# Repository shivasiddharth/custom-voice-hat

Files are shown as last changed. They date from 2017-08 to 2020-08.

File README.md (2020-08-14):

# custom-voice-hat
Create a custom Voice HAT, much like Google's VOICE HAT  

Use the below video for reference.     

<a href="http://www.youtube.com/watch?feature=player_embedded&v=GM1YbNMauck
" target="_blank">Detailed Youtube Video</a>

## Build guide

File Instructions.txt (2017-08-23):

# Parts List
1. Adafruit I2S MEMS Microphone Breakout - SPH0645LM4H - 2Nos - https://www.adafruit.com/product/3421
2. Adafruit I2S 3W Class D Amplifier Breakout - MAX98357A - 1No - https://www.adafruit.com/product/3006
3. Adafruit Perma-Proto HAT for Pi Mini Kit - With EEPROM - 1No - https://www.adafruit.com/product/2314

# Following steps to be completed on the Pi.

#Clone the project onto the pi
git clone https://github.com/shivasiddharth/custom-voice-hat

1. Turn on i2s support in /boot/config.txt with:
sudo nano /boot/config.txt

****Uncomment the following****
#dtparam=i2s=on
#dtparam=i2c_arm=on
#dtparam=spi=on
#dtparam=audio=on

****Add the following new entry****
dtparam=i2c_vc=on

Save Exit and Reboot.

2. Check for the Hats folder:
cd /proc/device-tree/

3. Open a new terminal and change directory to eepromutils:
cd /home/pi/custom-voice-hat/eepromutils

4. Make the EEPROM flasher executable and Flash the EEPROM with the eeprom file:
sudo chmod +x ./eepflash.sh
sudo ./eepflash.sh -w -f=voicehat.eep -t=24c32

5. Update raspberry pi kernels:
sudo apt-get update
sudo apt-get install raspberrypi-kernel

6. Reboot
sudo reboot

7. Check if your HAT is recognized,:
cd /proc/device-tree/

***YOU WILL HAVE A HAT FOLDER NOW WITH VOICE HAT DETAILS***

# Shutdown and Wire the Parts as indicated in the attached wiring diagram
***CAUTION- Amplifier board should be powered using 5V and the Mics using 3.3v***

# Start your Pi and move into the audio configuration scripts:
cd /home/pi/custom-voice-hat/audio-config/scripts/

#Make the scripts executable:
sudo chmod +x ./custom-voice-hat.sh
sudo chmod +x ./install-i2s.sh

#Run the Executable scripts
sudo ./custom-voice-hat.sh
sudo ./install-i2s.sh

****RUN THE custom-voice-hat.sh script untill you get .bak notification****
****REBOOT and Enjoy your HAT****

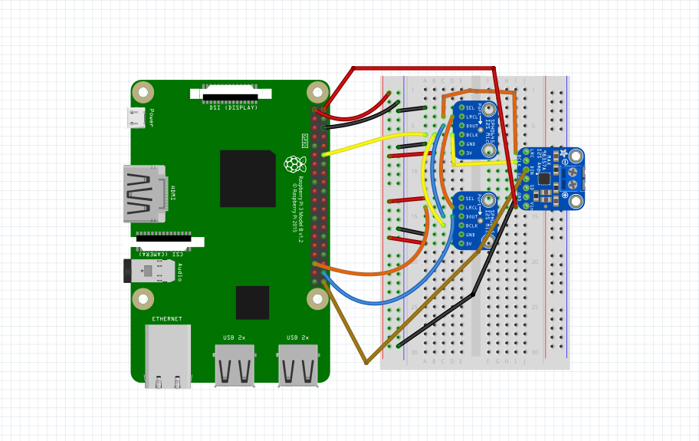
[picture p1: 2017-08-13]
Rpi-custom-voice-hat-wiring.png

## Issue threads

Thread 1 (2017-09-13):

Card 0 not found

kunallanjewar, 2017-09-13:
I followed the given instructions but getting following errors when I ran _./main.py -T ok-google_

Do I need to follow these instructions to install I2C microphone drivers?
https://learn.adafruit.com/adafruit-i2s-mems-microphone-breakout/raspberry-pi-wiring-and-test

**Error Log:**
[2017-09-12 22:22:27,683] INFO:recorder:started recording
[2017-09-12 22:22:27,714] INFO:main:ready...
Press the button on GPIO 23 then speak, or press Ctrl+C to quit...
ALSA lib confmisc.c:768:(parse_card) cannot find card '0'
ALSA lib conf.c:4259:(_snd_config_evaluate) function snd_func_card_driver returned error: No such file or directory
ALSA lib confmisc.c:392:(snd_func_concat) error evaluating strings
ALSA lib conf.c:4259:(_snd_config_evaluate) function snd_func_concat returned error: No such file or directory
ALSA lib confmisc.c:1251:(snd_func_refer) error evaluating name
ALSA lib conf.c:4259:(_snd_config_evaluate) function snd_func_refer returned error: No such file or directory
ALSA lib conf.c:4738:(snd_config_expand) Evaluate error: No such file or directory
ALSA lib pcm.c:2239:(snd_pcm_open_noupdate) Unknown PCM dsnoop
arecord: main:722: audio open error: No such file or directory
[2017-09-12 22:22:27,848] ERROR:recorder:Microphone recorder died unexpectedly, aborting...

kunallanjewar, 2017-09-13:
Figured it out. I had google-voice-hat commented in config.txt

Closed 2017-09-13.

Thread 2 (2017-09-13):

Only one mic is working?

kunallanjewar, 2017-09-13:
I followed all instruction and made sure i followed them currently, including the wiring of both microphones and the amp.

However, when I run following command, I can only see one mic working. I was wondering if both mics work for you?

`arecord -D plughw:0 -c2 -r 48000 -f S32_LE -t wav -V stereo -v file_stereo.wav`

shivasiddharth, 2017-09-27:
Sorry for getting back late. Missed this somehow.
I had the same suspicion , so i checked out the original AIY HAT that i have me just after i got his custom HAT done. Even in that, two channels are multiplexed into one. The google assistant does not recognize stereo microphone audio. May be thats the reason they have done this intentionally. Or the speaker amp sharing the clock pulse also could be the reason.

Closed 2018-02-20.

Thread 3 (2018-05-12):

which info is stored in the voicehat.eep file?

nivw, 2018-05-12:
Hi Sid,
I am looking to use a microphone and a speaker with I2S, as you did here.
I found little info on the web, on how to achieve this, and many folks asked about it.
So I looked to see what you used in your voicehat.eep.
I read [This](https://github.com/raspberrypi/hats/blob/master/eeprom-format.md) and can understand the first part of the eeprom:
` hexdump -C voicehat.eep
00000000  52 2d 50 69 01 00 02 00  7c 00 00 00 01 00 00 00  |R-Pi....|.......|
00000010  40 00 00 00 5e 69 95 06  36 73 da 92 91 42 be 31  |@...^i..6s...B.1|
00000020  52 b7 df 0d 01 00 01 00  0c 1c 47 6f 6f 67 6c 65  |R.........Google|
00000030  2c 20 49 6e 63 2e 47 6f  6f 67 6c 65 20 41 49 59  |, Inc.Google AIY|
00000040  20 61 75 64 69 6f 48 41  54 20 42 6f 61 72 64 20  | audioHAT Board |
00000050  76 31 92 90 02 00 01 00  20 00 00 00 00 00 00 00  |v1...... .......|
00000060  00 00 00 00 00 00 00 00  00 00 00 00 00 00 00 00  |................|
00000070  00 00 00 00 00 00 00 00  00 00 ed 6e ff ff ff ff  |...........n....|
00000080  ff ff ff ff ff ff ff ff  ff ff ff ff ff ff ff ff  |................|
*
00001000
`

Your vendor info atom data is clear, but I don't understand the GPIO and the device tree. in facat I see no device tree 0x0003 type at all.
So what is the GPIO setup and what device tree do you use?
Thank you very much for sharing this great project.
Niv

diabl0w, 2020-08-14:
hi, did you ever get this to work? I am trying to get the microphones and speaker output over i2s at the same time, but my speakers arent working. I can't tell if its a wiring issue or an eeprom issue or a kernel limitation issue

shivasiddharth, 2020-08-14:
@diabl0w I am still using the same custom hat even after so many updates and upgrades to the OS. I first flashed the EEPROM before wiring anything. And then went through the audio setup process. At this point if the flashing was done properly, you should see the DAC listed when you use the `asound -l` and `arecord -l` commands. Also, you should see the device tree. Only after verifying this you should wire the parts. I have shown this all in the video attached in the README.

shivasiddharth, 2020-08-14:
Try the method here if you are not using the EEPROM https://www.hackster.io/maremoto/snips-assistant-for-emergencies-safe-c3c178#toc-satellite-preparation-3

diabl0w, 2020-08-14:
> @diabl0w I am still using the same custom hat even after so many updates and upgrades to the OS. I first flashed the EEPROM before wiring anything. And then went through the audio setup process. At this point if the flashing was done properly, you should see the DAC listed when you use the `asound -l` and `arecord -l` commands. Also, you should see the device tree. Only after verifying this you should wire the parts. I have shown this all in the video attached in the README.

Thank you so much! I got it working and I am loving it! One problem I am having:

If I use a pcm5102a DAC both microphone and speaker work great! However, I wanted to use a better DAC, so I tried using an "Allo Boss" clone. If I use that, i only either get microphone or speaker, never both. Because the Allo Boss requires its own "dtoverlay", so whatever one i put second in "/boot/config.txt" works. The AlloBoss does not have its own eeprom, but it does use SDA/SCL, but at a different address (0x4d) and not our address of 0x50

diabl0w, 2020-08-14:
Okay, I think I know the issue. The issue is that the Allo Boss uses PCM5122. The PCM5122 can use i2s either over the actual i2s interface or i2s via spi. The allo boss has it configured to use the native i2s-1 pins (pins 3 and 5 on pi). The PCM5102 on the other hand uses i2s over spi.

So, that is the problem, but I do not know the solution. Can our hat coexist with the allo boss both using actual i2s? Or I can pull one of the headers on the Allo Boss to high which will make it work in spi mode like the pcm5102.

Id rather not have to modify the Allo Boss board

shivasiddharth, 2020-08-14:
Do check the pinout for that Allo DAC to see if there is any overlap with the Mics. You cna use other DACs like pHAT DAC, etc. I have tested it and it works. https://www.youtube.com/watch?v=m2aSVqBKY4Y

diabl0w, 2020-08-14:
The issue has something to do with

> pHAT DAC

yes, that is because that dac also uses the "PCM5102". The issue I am running into is that the Allo Boss uses a PCM5122, and it also has its own clock. I think the solution would be creating a custom dtoverlay/dts. Unfortunately, that is over my head of knowledge. But thank you for your help, I am still quite satisfied with the setup you provided :)

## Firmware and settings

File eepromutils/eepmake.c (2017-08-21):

/*
 *	Parses EEPROM text file and createds binary .eep file
 *	Usage: eepmake input_file output_file
*/

#include <stdio.h>
#include <stdlib.h>
#include <ctype.h>
#include <string.h>
#include <stdbool.h>
#include <fcntl.h>

#include "eeptypes.h"

#define HEADER_SIGN 0x69502d52 //"R-Pi" in ASCII reversed for endianness

//todo: larger initial mallocs

struct header_t header;
struct atom_t *custom_atom, vinf_atom, gpio_atom, dt_atom;
struct vendor_info_d* vinf;
struct gpio_map_d* gpiomap;

bool product_serial_set, product_id_set, product_ver_set, vendor_set, product_set, 
			gpio_drive_set, gpio_slew_set, gpio_hysteresis_set, gpio_power_set;
			
bool data_receive, has_dt, receive_dt;
			
char **data;
char *current_atom; //rearranged to write out
unsigned int data_len, custom_ct, total_size, data_cap, custom_cap;


int write_binary(char* out) {
	FILE *fp;
	int i, offset;
	short crc;
	
	fp=fopen(out, "wb");
	if (!fp) {
		printf("Error writing file %s\n", out);
		return -1;
	}
	
	fwrite(&header, sizeof(header), 1, fp);
		
		
	current_atom = (char *) malloc(vinf_atom.dlen+ATOM_SIZE-CRC_SIZE);
	offset = 0;
	//vendor information atom first part
	memcpy(current_atom, &vinf_atom, ATOM_SIZE-CRC_SIZE);
	offset += ATOM_SIZE-2;
	//data first part
	memcpy(current_atom+offset, vinf_atom.data, VENDOR_SIZE);
	offset += VENDOR_SIZE;	
	//data strings
	memcpy(current_atom+offset, vinf->vstr, vinf->vslen);
	offset += vinf->vslen;
	memcpy(current_atom+offset, vinf->pstr, vinf->pslen);
	offset += vinf->pslen;
	//vinf last part
	crc = getcrc(current_atom, offset);
	memcpy(current_atom+offset, &crc, CRC_SIZE);
	offset += CRC_SIZE;
	
	fwrite(current_atom, offset, 1, fp);
	free(current_atom);
	
	current_atom = (char *) malloc(gpio_atom.dlen+ATOM_SIZE-CRC_SIZE);
	offset = 0;
	//GPIO map first part
	memcpy(current_atom, &gpio_atom, ATOM_SIZE-CRC_SIZE);
	offset += ATOM_SIZE-CRC_SIZE;
	//GPIO data
	memcpy(current_atom+offset, gpiomap, GPIO_SIZE);
	offset += GPIO_SIZE;
	//GPIO map last part
	crc = getcrc(current_atom, offset);
	memcpy(current_atom+offset, &crc, CRC_SIZE);
	offset += CRC_SIZE;
	
	fwrite(current_atom, offset, 1, fp);
	free(current_atom);
	
	if (has_dt) {
		printf("Writing out DT...\n");
		current_atom = (char *) malloc(dt_atom.dlen+ATOM_SIZE-CRC_SIZE);
		offset = 0;
		
		memcpy(current_atom, &dt_atom, ATOM_SIZE-CRC_SIZE);
		offset += ATOM_SIZE-CRC_SIZE;
		
		memcpy(current_atom+offset, dt_atom.data, dt_atom.dlen-CRC_SIZE);
		offset += dt_atom.dlen-CRC_SIZE;
		
		crc = getcrc(current_atom, offset);
		memcpy(current_atom+offset, &crc, CRC_SIZE);
		offset += CRC_SIZE;
		
		fwrite(current_atom, offset, 1, fp);
		free(current_atom);
	}
	
	for (i = 0; i<custom_ct; i++) {
		custom_atom[i].count-=!has_dt;
		
		current_atom = (char *) malloc(custom_atom[i].dlen+ATOM_SIZE-CRC_SIZE);
		offset = 0;
		
		memcpy(current_atom, &custom_atom[i], ATOM_SIZE-CRC_SIZE);
		offset += ATOM_SIZE-CRC_SIZE;
		
		memcpy(current_atom+offset, custom_atom[i].data, custom_atom[i].dlen-CRC_SIZE);
		offset += custom_atom[i].dlen-CRC_SIZE;
		
		crc = getcrc(current_atom, offset);
		memcpy(current_atom+offset, &crc, CRC_SIZE);
		offset += CRC_SIZE;
		
		fwrite(current_atom, offset, 1, fp);
		free(current_atom);
	}
	
	
	fflush(fp);
	fclose(fp);
	return 0;
}


void parse_data(char* c) {
	int k;
	char s;
	char* i = c;
	char* j = c;
	while(*j != '\0')
	{
		*i = *j++;
		if(isxdigit(*i))
			i++;
	}
	*i = '\0';
	
	int len = strlen(c);
	if (len % 2 != 0) {
		printf("Error: data must have an even number of hex digits\n");
	} else {
		for (k = 0; k<len/2; k++) {
			//read a byte at a time
			s = *(c+2);
			*(c+2)='\0';
			
			if (data_len==data_cap) {
				data_cap *=2;
				*data = (char *) realloc(*data, data_cap);
			}
			
			sscanf(c, "%2x", *data+data_len++);
			
			*(c+2) = s;
			c+=2;
		}
	}
}


void finish_data() {
	if (data_receive) {
		*data = (char *) realloc(*data, data_len);
			
		total_size+=ATOM_SIZE+data_len;

		if (receive_dt) {
			dt_atom.type = ATOM_DT_TYPE;
			dt_atom.count = ATOM_DT_NUM;
			dt_atom.dlen = data_len+CRC_SIZE;
		} else {
			//finish atom description
			custom_atom[custom_ct].type = ATOM_CUSTOM_TYPE;
			custom_atom[custom_ct].count = 3+custom_ct;
			custom_atom[custom_ct].dlen = data_len+CRC_SIZE;
			
			custom_ct++;
		}
	}
}


void parse_command(char* cmd, char* c) {
	int val;
	uint32_t high1, high2;
	char *fn, *pull;
	char pin;
	bool valid;
	bool continue_data=false;
	
	/* Vendor info related part */
	if (strcmp(cmd, "product_uuid")==0) {
		product_serial_set = true; //required field
		high1 = 0; high2 = 0;
		
		sscanf(c, "%100s %08x-%04x-%04x-%04x-%04x%08x\n", cmd, &vinf->serial_4, 
			&high1, &vinf->serial_3, &high2, &vinf->serial_2, &vinf->serial_1);
		
		vinf->serial_3 |= high1<<16;
		vinf->serial_2 |= high2<<16;
		
		if ((vinf->serial_4==0) && (vinf->serial_3==0) && (vinf->serial_2==0) && (vinf->serial_1==0)) {
			//read 128 random bits from /dev/urandom
			int random_file = open("/dev/urandom", O_RDONLY);
			ssize_t result = read(random_file, &vinf->serial_1, 16);
			close(random_file);
			if (result <= 0) printf("Unable to read from /dev/urandom to set up UUID");
			else {
				//put in the version
				vinf->serial_3 = (vinf->serial_3 & 0xffff0fff) | 0x00004000;
				
				//put in the variant
				vinf->serial_2 = (vinf->serial_2 & 0x3fffffff) | 0x80000000;
				
				printf("UUID=%08x-%04x-%04x-%04x-%04x%08x\n", vinf->serial_4, vinf->serial_3>>16, vinf->serial_3 & 0xffff, vinf->serial_2>>16, vinf->serial_2 & 0xffff, vinf->serial_1);
			}
 
		}
		
	} else if (strcmp(cmd, "product_id")==0) {
		product_id_set = true; //required field
		sscanf(c, "%100s %hx", cmd, &vinf->pid);
		
	} else if (strcmp(cmd, "product_ver")==0) {
		product_ver_set = true; //required field
		sscanf(c, "%100s %hx", cmd, &vinf->pver);
		
	} else if (strcmp(cmd, "vendor")==0) {
		vendor_set = true; //required field
		
		vinf->vstr = (char*) malloc (256);
		sscanf(c, "%100s \"%255[^\"]\"", cmd, vinf->vstr);
		
		total_size-=vinf->vslen;
		vinf_atom.dlen-=vinf->vslen;
		
		vinf->vslen = strlen(vinf->vstr);
		
		total_size+=vinf->vslen;
		vinf_atom.dlen+=vinf->vslen;
		
	} else if (strcmp(cmd, "product")==0) {
		product_set = true; //required field
		
		vinf->pstr = (char*) malloc (256);
		sscanf(c, "%100s \"%255[^\"]\"", cmd, vinf->pstr);
		
		total_size-=vinf->pslen;
		vinf_atom.dlen-=vinf->pslen;
		
		vinf->pslen = strlen(vinf->pstr);
		
		total_size+=vinf->pslen;
		vinf_atom.dlen+=vinf->pslen;
	} 
	
	/* GPIO map related part */
	else if (strcmp(cmd, "gpio_drive")==0) {
		gpio_drive_set = true; //required field
		
		sscanf(c, "%100s %1x", cmd, &val);
		if (val>8 || val<0) printf("Warning: gpio_drive property in invalid region, using default value instead\n");
		else gpiomap->flags |= val;
		
		
	} else if (strcmp(cmd, "gpio_slew")==0) {
		gpio_slew_set = true; //required field
		
		sscanf(c, "%100s %1x", cmd, &val);
		
		if (val>2 || val<0) printf("Warning: gpio_slew property in invalid region, using default value instead\n");
		else gpiomap->flags |= val<<4;
		
	} else if (strcmp(cmd, "gpio_hysteresis")==0) {
		gpio_hysteresis_set = true; //required field
		
		sscanf(c, "%100s %1x", cmd, &val);
		
		if (val>2 || val<0) printf("Warning: gpio_hysteresis property in invalid region, using default value instead\n");
		else gpiomap->flags |= val<<6;
		
	} else if (strcmp(cmd, "back_power")==0) {
		gpio_power_set = true; //required field
		
		sscanf(c, "%100s %1x", cmd, &val);
		
		if (val>2 || val<0) printf("Warning: back_power property in invalid region, using default value instead\n");
		else gpiomap->power = val;
		
	} else if (strcmp(cmd, "setgpio")==0) {
		fn = (char*) malloc (101);
		pull = (char*) malloc (101);
		
		sscanf(c, "%100s %d %100s %100s", cmd, &val, fn, pull);
		
		if (val<GPIO_MIN || val>=GPIO_COUNT) printf("Error: GPIO number out of bounds\n");
		else {
			valid = true;
			pin = 0;
			
			if (strcmp(fn, "INPUT")==0) {
				//no action
			} else if (strcmp(fn, "OUTPUT")==0) {
				pin |= 1;
			} else if (strcmp(fn, "ALT0")==0) {
				pin |= 4;
			} else if (strcmp(fn, "ALT1")==0) {
				pin |= 5;
			} else if (strcmp(fn, "ALT2")==0) {
				pin |= 6;
			} else if (strcmp(fn, "ALT3")==0) {
				pin |= 7;
			} else if (strcmp(fn, "ALT4")==0) {
				pin |= 3;
			} else if (strcmp(fn, "ALT5")==0) {
				pin |= 2;
			} else {
				printf("Error at setgpio: function type not recognised\n");
				valid=false;
			}
			
			if (strcmp(pull, "DEFAULT")==0) {
				//no action
			} else if (strcmp(pull, "UP")==0) {
				pin |= 1<<5;
			} else if (strcmp(pull, "DOWN")==0) {
				pin |= 2<<5;
			} else if (strcmp(pull, "NONE")==0) {
				pin |= 3<<5;
			} else {
				printf("Error at setgpio: pull type not recognised\n");
				valid=false;
			}
			
			pin |= 1<<7; //board uses this pin
			
			if (valid) gpiomap->pins[val] = pin;
		}
	} 
	
	/* DT atom related part */
	else if (strcmp(cmd, "dt_blob")==0) {
		finish_data();
		
		has_dt = true;
		c+=strlen("dt_blob");
		
		receive_dt=true;
		data_receive=true;
		
		data_len = 0;
		data_cap = 4;
		data = &dt_atom.data;
		*data = (char *) malloc(data_cap);
		
		parse_data(c);
		continue_data = true;
	
	} 
	
	/* Custom data related part */
	else if (strcmp(cmd, "custom_data")==0) {
		finish_data();
		
		c+=strlen("custom_data");
		
		if (custom_cap == custom_ct) {
			custom_cap *= 2;
			custom_atom = (struct atom_t*) realloc(custom_atom, custom_cap * sizeof(struct atom_t));
		}
		
		receive_dt=false;
		data_receive=true;
		
		data_len = 0;
		data_cap = 4;
		data = &custom_atom[custom_ct].data;
		*data = (char *) malloc(data_cap);
		
		parse_data(c);
		continue_data = true;
	
	} else if (strcmp(cmd, "end") ==0) {
		//close last data atom
		continue_data=false;
	}
	/* Incoming data */
	else if (data_receive) {
		parse_data(c);
		continue_data = true;
	} 
	
	
	if (!continue_data) finish_data();
	
}

int read_text(char* in) {
	FILE * fp;
	char * line = NULL;
	char * c = NULL;
	size_t len = 0;
	ssize_t read;
	char *comment = NULL;
	int atomct = 2;
	int linect = 0;
	char * command = (char*) malloc (101);
	int i;
	
	has_dt = false;
	
	printf("Opening file %s for read\n", in);
	
	fp = fopen(in, "r");
	if (fp == NULL) {
		printf("Error opening input file\n");
		return -1;
	}

	//allocating memory and setting up required atoms
	custom_cap = 1;
	custom_atom = (struct atom_t*) malloc(sizeof(struct atom_t) * custom_cap);
	
	total_size=ATOM_SIZE*2+HEADER_SIZE+VENDOR_SIZE+GPIO_SIZE;
	
	vinf_atom.type = ATOM_VENDOR_TYPE;
	vinf_atom.count = ATOM_VENDOR_NUM;
	vinf = (struct vendor_info_d *) malloc(sizeof(struct vendor_info_d));
	vinf_atom.data = (char *)vinf;
	vinf_atom.dlen = VENDOR_SIZE + CRC_SIZE;
	
	gpio_atom.type = ATOM_GPIO_TYPE;
	gpio_atom.count = ATOM_GPIO_NUM;
	gpiomap = (struct gpio_map_d *) malloc(sizeof(struct gpio_map_d));
	gpio_atom.data = (char *)gpiomap;
	gpio_atom.dlen = GPIO_SIZE + CRC_SIZE;
	
	while ((read = getline(&line, &len, fp)) != -1) {
		linect++;
		c = line;
		
		for (i=0; i<read; i++) if (c[i]=='#') c[i]='\0';
		
		while (isspace(*c)) ++c;
		
		
		if (*c=='\0' || *c=='\n' || *c=='\r') {
			//empty line, do nothing
		} else if (isalnum (*c)) {
			sscanf(c, "%100s", command);
			
#ifdef DEBUG
			printf("Processing line %u: %s", linect, c);
			if ((*(c+strlen(c)-1))!='\n') printf("\n");
#endif
			
			parse_command(command, c);
		
		
		} else printf("Can't parse line %u: %s", linect, c);
	}
	
	finish_data();
	
	if (!product_serial_set || !product_id_set || !product_ver_set || !vendor_set || !product_set || 
			!gpio_drive_set || !gpio_slew_set || !gpio_hysteresis_set || !gpio_power_set) {
			
		printf("Warning: required fields missing in vendor information or GPIO map, using default values\n");
	}
	
	printf("Done reading\n");
	
	return 0;
}


int read_dt(char* in) {
	FILE * fp;
	unsigned long size = 0;
	
	printf("Opening DT file %s for read\n", in);
	
	fp = fopen(in, "r");
	if (fp == NULL) {
		printf("Error opening input file\n");
		return -1;
	}
	
	fseek(fp, 0L, SEEK_END);
	size = ftell(fp);
	fseek(fp, 0L, SEEK_SET);
	
	printf("Adding %lu bytes of DT data\n", size);
	
	total_size+=ATOM_SIZE+size;
	has_dt = true;
	dt_atom.type = ATOM_DT_TYPE;
	dt_atom.count = ATOM_DT_NUM;
	dt_atom.dlen = size+CRC_SIZE;
	
	dt_atom.data = (char *) malloc(size);
	if (!fread(dt_atom.data, size, 1, fp)) goto err;
	
	
	fclose(fp);
	return 0;
	
err:
	printf("Unexpected EOF or error occurred\n");
	fclose(fp);
	return 0;
	
}

int read_custom(char* in) {
	FILE * fp;
	unsigned long size = 0;
	
	printf("Opening custom data file %s for read\n", in);
	
	fp = fopen(in, "r");
	if (fp == NULL) {
		printf("Error opening input file\n");
		return -1;
	}
	
	fseek(fp, 0L, SEEK_END);
	size = ftell(fp);
	fseek(fp, 0L, SEEK_SET);
	
	printf("Adding %lu bytes of custom data\n", size);
	
	total_size+=ATOM_SIZE+size;
	
	custom_atom[custom_ct].type = ATOM_CUSTOM_TYPE;
	custom_atom[custom_ct].count = 3+custom_ct;
	custom_atom[custom_ct].dlen = size+CRC_SIZE;
	
	custom_atom[custom_ct].data = (char *) malloc(size);
	if (!fread(custom_atom[custom_ct].data, size, 1, fp)) goto err;
	
	custom_ct++;
	
	fclose(fp);
	return 0;
	
err:
	printf("Unexpected EOF or error occurred\n");
	fclose(fp);
	return 0;
	
}
int main(int argc, char *argv[]) {
	int ret;
	int i, custom_o=0;
	
	if (argc<3) {
		printf("Wrong input format.\n");
		printf("Try 'eepmake input_file output_file [dt_file] [-c custom_file_1 ... custom_file_n]'\n");
		return 0;
	}
	
	
	ret = read_text(argv[1]);
	if (ret) {
		printf("Error reading and parsing input, aborting\n");
		return 0;
	}
	
	if (argc>3) {
		if (strcmp(argv[3], "-c")==0) {
			custom_o=4;
		} else {
			//DT file specified
			if (dt_atom.dlen) total_size-=(ATOM_SIZE +dt_atom.dlen - CRC_SIZE);
			ret = read_dt(argv[3]);
			if (ret) {
				printf("Error reading DT file, aborting\n");
				return 0;
			}
		}
	}
	
	if (argc>4 && strcmp(argv[4], "-c")==0) custom_o = 5;

	if (custom_o)
		for (i = custom_o; i<argc; i++) {
			//new custom data file
			ret = read_custom(argv[i]);
			if (ret) {
				printf("Error reading DT file, aborting\n");
				return 0;
			}
		}
	
	header.signature = HEADER_SIGN;
	header.ver = FORMAT_VERSION;
	header.res = 0;
	header.numatoms = 2+has_dt+custom_ct;
	header.eeplen = total_size;
	
	printf("Writing out...\n");
	
	ret = write_binary(argv[2]);
	if (ret) {
		printf("Error writing output\n");
		return 0;
	}
	
	printf("Done.\n");

	return 0;
}
